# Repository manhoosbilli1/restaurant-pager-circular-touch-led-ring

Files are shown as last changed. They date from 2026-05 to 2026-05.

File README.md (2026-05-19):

# Restaurant Pager — Circular Touch + LED Ring

ESP32-controlled circular restaurant table pager: a central capacitive **TOUCH** pad surrounded by a 16-LED ring of WS2812B addressable RGBs, plus a **MIC** for audio.

Designed in EasyEDA Pro. Sources here are the **KiCad-converted** form produced by `_backup-tooling/epcb_to_kicad.py` and `_backup-tooling/esch_to_kicad_sch.py`. Original EasyEDA `.epro` archive preserved in `source/` for re-editing.

## At a Glance

- **Board size**: 60 × 60 mm, 4-layer
- **Components**: 101 placed, 17× WS2812B-2020 addressable LEDs forming a ring around a central capacitive touch pad
- **Tracks**: 1,051 (top + bottom)
- **Vias**: 288 (0.305 mm drill / 0.61 mm pad)
- **Copper zones**: 18 (GND + power pours)
- **Schematic**: 200 component instances (101 placed + power/test points), 405 wires
- **Status**: Routed and assembled (manufactured version)

## Renders

3D models for **48 of 101 components** come from the LCSC library (fetched via easyeda2kicad). The ESP32-S3 module, JST-PH connectors, USB-C receptacle, MIC package, and LED bodies are visible with real geometry. The remaining components fall back to flat pad placeholders.

### 3D top (controller side)
The labelled side: PWR / STATUS / 5V / GND / CHG / EXT TOUCH / LED OUT / BAT / VBAT / USB / SPKR / 3V3 / BOOT / RESET test points around the **ESP32-S3 module** (top), JST-PH connectors (left + right), USB-C (bottom right).

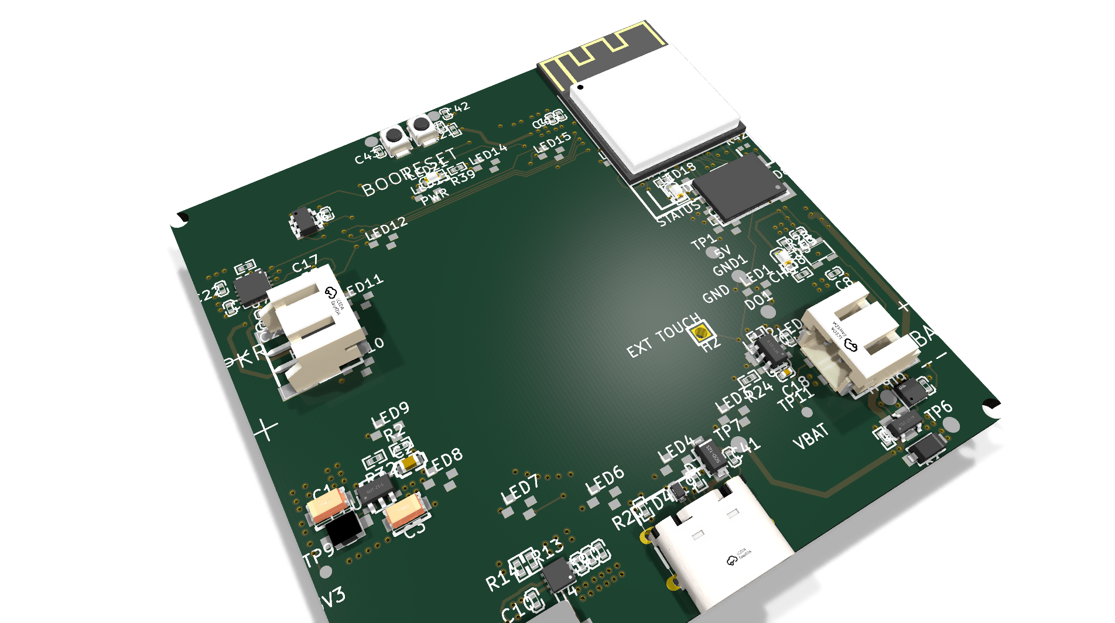
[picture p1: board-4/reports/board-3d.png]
3D top


### 3D bottom (sensor side)
The user-facing side: central round **TOUCH** pad with a ring of 16 WS2812B-2020 RGB LEDs (real 3D bodies visible), **MIC** package on the side, 4 corner mounting/test pads.

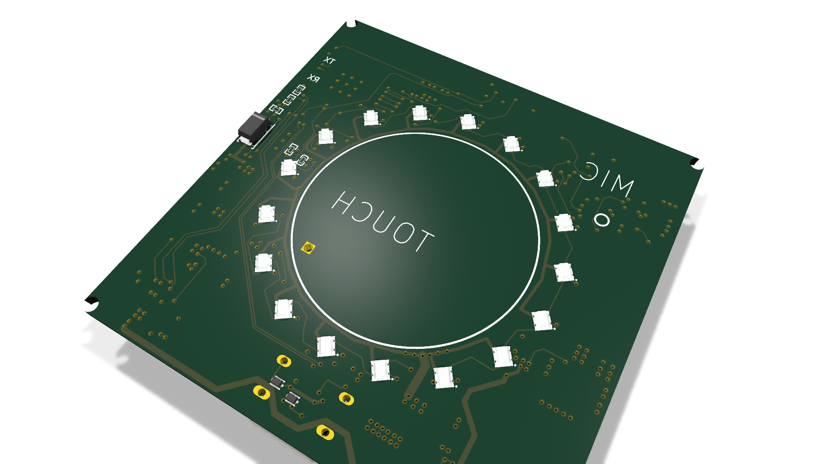
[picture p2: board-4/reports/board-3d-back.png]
3D bottom


## Schematic

Converted from EasyEDA `.esch` to KiCad 10 `.kicad_sch`. **39 of 44 unique component symbols use real geometry parsed from the EasyEDA `.esym` source files** (matching pin counts, pin positions, body rectangles). The remaining 5 fall back to generic KiCad library symbols.

Also extracted from `.esch`: **154 NET labels** on wire endpoints, **17 global labels** (power rails: 3V3, 5V, GND, VBAT, etc.), **27 no-connect markers**, and **405 wire segments** — preserving the exact connectivity of the original.

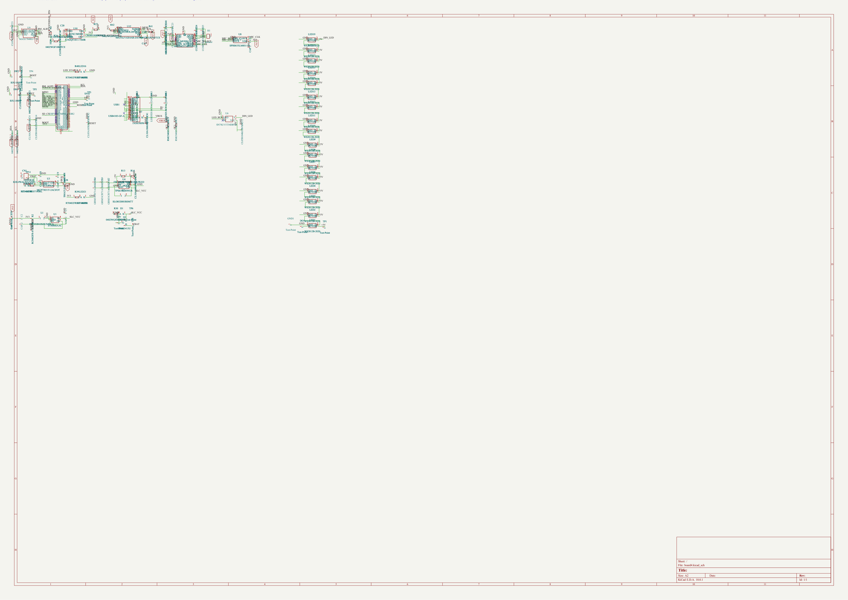
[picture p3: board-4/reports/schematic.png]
Schematic


Full vector PDF: [board-4/reports/schematic.pdf](board-4/reports/schematic.pdf)

## Files

- `board-4/board4.kicad_pcb` — KiCad 10 PCB layout (converted from `.epcb`)
- `board-4/board4.kicad_sch` — KiCad 10 schematic (converted from `.esch`)
- `board-4/reports/board-3d.png`, `board-3d-back.png` — angled raytraced 3D views
- `board-4/reports/pcb-top.svg`, `pcb-bottom.svg` — copper artwork
- `board-4/reports/schematic.pdf`, `schematic.png` — schematic in PDF + raster
- `board-4/reports/bom.csv` — 101-component BOM with MPN-ish library references (most include LCSC codes)
- `board-4/reports/board-stats.json` — KiCad-computed board statistics
- `source/Restaurant table pager circular.epro` — original EasyEDA Pro project archive
- `source/` also holds the source dump if you re-extract; original lives at the .epro zip

## How this repo was produced

The conversion pipeline lives at `_backup-tooling/` in the parent workspace:

```bash
# 1. PCB conversion (EasyEDA Pro .epcb -> .kicad_pcb)
python epcb_to_kicad.py source/extracted/PCB/<pcb-uuid>.epcb \
    -o board-4/board4.kicad_pcb \
    --footprint-dir source/extracted/FOOTPRINT \
    --project-json source/extracted/project.json \
    --title "Restaurant Pager Circular - Board 4"

# 2. Schematic conversion (EasyEDA Pro .esch -> .kicad_sch, KiCad 10 format)
python esch_to_kicad_sch.py source/extracted/SHEET/<sheet-uuid>/1.esch \
    -o board-4/board4.kicad_sch

# 3. Render artifacts via kicad-cli (3D PNGs, copper SVGs, schematic PDF)
kicad-cli pcb render --rotate -30,0,30 --quality high --floor --perspective \
    -w 1920 -h 1080 --side top -o board-4/reports/board-3d.png board-4/board4.kicad_pcb
kicad-cli sch export pdf -o board-4/reports/schematic.pdf board-4/board4.kicad_sch
```

Schematic emitter patterns are based on [eencyclopedia/lib/kicad/fromEditorState.ts](https://github.com/manhoosbilli1) — a hand-rolled, test-covered KiCad 10 writer.

## Caveats (Phase 1 conversion)

- **101/101 components rendered** on PCB (real pad geometry from `.efoo` library + embedded test-point footprints). Some component rotations or silkscreen positions may be slightly off from the original due to coordinate-frame conventions — this is a known issue in the converter, see `_backup-tooling/epcb_to_kicad.py`.
- **Schematic component symbols** are generic KiCad library placeholders, not full visual replicas of the EasyEDA symbols (would need a per-symbol mapping table).
- **Net connectivity** is preserved at the data level (PAD_NET records → KiCad net IDs) but won't pass DRC/ERC as-is.
- The `.epro` archive in `source/` is the authoritative original — re-import to EasyEDA Pro for any active editing.

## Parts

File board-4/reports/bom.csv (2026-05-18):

Designator | LibReference (MPN-ish) | Comment/Value | Footprint | Description
C1 | CA45-A-16V-10uF-K_C185774 | 10uF
CN1 | S2B-PH-SM4-TB(LF)(SN)
C2 | AC0603JRNPO9BN220 | 22pF
C3 | CA45-A-16V-10uF-K_C185774 | 10uF
C4 | 0402ZD106MAT2A | 10uF
C7 | 04026D226MAT2A | 22uF
C8 | 0402X475K100NT | 4.7uF
C9 | 0402X475K100NT | 4.7uF
C10 | 0402ZD106MAT2A | 10uF
C12 | CL05B104KO5NNNC | 100nF
C14 | CL05B104KB54PNC | 100nF
C15 | CL05B104KB54PNC | 100nF
C17 | CT41G-0402-2X1-16V-0.1uF-K(N) | 100nF
C18 | CL05B103KB5NNNC | 10nF
C20 | CL05B104KB54PNC | 100nF
C21 | CL05B104KB54PNC | 100nF
C22 | 0402ZD106MAT2A | 10uF
C23 | CL05B104KB54PNC | 100nF
C24 | 0402N221G500CT | 220pF
C25 | 0402N221G500CT | 220pF
C39 | 04026D226MAT2A | 22uF
C40 | 04026D226MAT2A | 22uF
C41 | 0402ZD106MAT2A | 10uF
C42 | CL05A105KP5NNNC | 1uF
C43 | CL05B104KB54PNC | 100nF
C44 | CT41G-0402-2X1-16V-0.1uF-K(N) | 100nF
D1 | B5819W_C64885
DO1 | Test-Point
D4 | LESD5D5.0CT1G_C41399463
D5 | LESD5D5.0CT1G_C41399463
D6 | LESD5D5.0CT1G_C41399463
D7 | 1N5819HW-7-F
D8 | SMAJ5.0A_C5249616
GND1 | Test-Point
H1 | S2B-PH-SM4-TB(LF)(SN)
H2 | HDR-M_2.54_1x1P
L1 | FTC252012S2R2MBCA | 2.2uH
LED1 | WS2812B-2020
L2 | SLO0520H1R0MTT | 1uH
LED2 | WS2812B-2020
LED3 | WS2812B-2020
LED4 | WS2812B-2020
LED5 | KT-0603R
LED6 | WS2812B-2020
LED7 | WS2812B-2020
LED8 | WS2812B-2020
LED9 | WS2812B-2020
LED10 | WS2812B-2020
LED11 | WS2812B-2020
LED12 | WS2812B-2020
LED13 | WS2812B-2020
LED14 | WS2812B-2020
LED15 | WS2812B-2020
LED16 | KT-0603R
LED17 | WS2812B-2020
LED18 | WS2812B-2020
LED19 | WS2812B-2020
LED21 | KT-0603R
Q1 | DMG3415U
R2 | RC0402FR-07100KL
R13 | AC0402FR-07732KL
R14 | CRCW0402100KFKED
R17 | 0402WGJ0103TCE
R18 | 0402WGJ0103TCE
R19 | RMC04025.1K5%N
R20 | RMC04025.1K5%N
R21 | 0402WGJ0103TCE
R24 | SCR0402F10K
R27 | SCR0402J0R
R28 | RC0402FR-071KL
R30 | 0402WGJ0103TCE
R32 | RC0402FR-0722K1L
R35 | 0402WGF1004TCE
R38 | RT0402FRE07140RL
R39 | RT0402FRE07140RL
R40 | RT0402FRE07140RL
R41 | 0402WGJ0103TCE
R42 | 0402WGJ0103TCE
SW1 | B3U-1000P_C231329
SW2 | B3U-1000P_C231329
TP1 | Test-Point
TP3 | Test-Point
TP4 | Test-Point
TP5 | Test-Point
TP6 | Test-Point
TP7 | Test-Point
TP8 | Test-Point
TP9 | Test-Point
TP10 | Test-Point
TP11 | Test-Point
U1 | SY8088IAAC
USB1 | USB4105-GF-A
U3 | MCP73831T-2ACI/OT
U4 | TPS61022RWUR
U5 | ESP32-S3-MINI-1-N4R2
U6 | SN74LV1T34DBVR_RF v1.0
U7 | MAX98357AETE+T
U8 | SPH0655LM4H-1-8
U9 | MAX17048G+T10
U10 | AT42QT1011-TSHR
U12 | MX35LF1GE4AB-Z4ITR

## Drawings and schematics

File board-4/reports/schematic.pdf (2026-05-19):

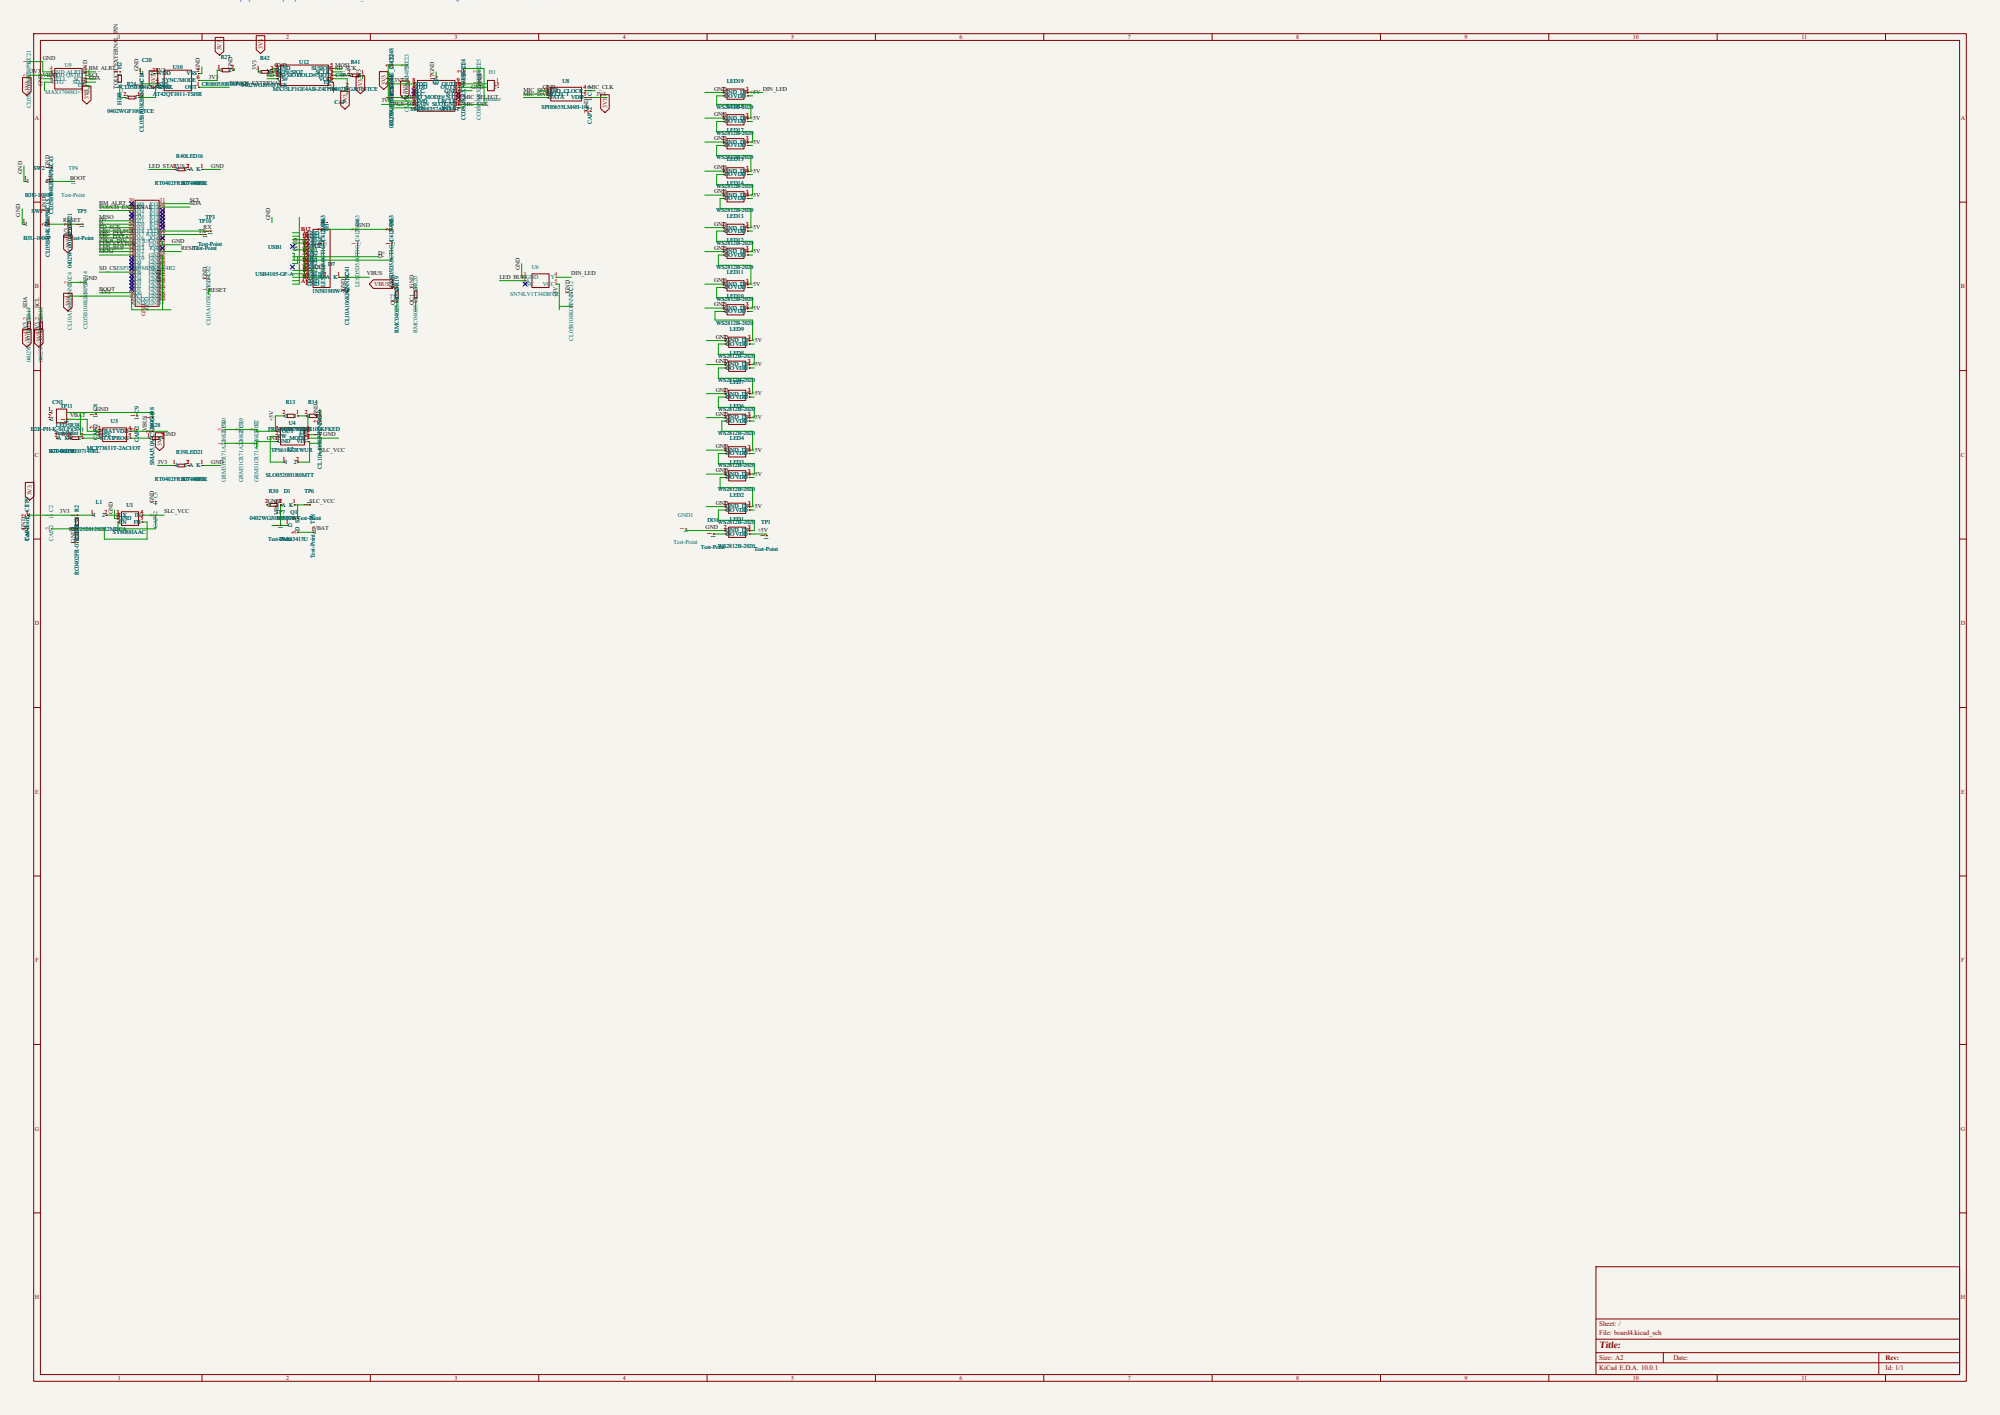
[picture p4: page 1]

1 TP4 Test-Point CS# 1SO/SIO1 2WP#/SIO2 3GND 4 SI/SIO05 SCLK6 HOLD#/SIO37 VCC8 EP9 U12 MX35LF1GE4AB-Z4ITR DIN 1GAIN_SLOT 2GND 3SD_MODE# 4N.C. 5

2 LED19 WS2812B-2020 DO 1GND 2 DI3 VDD4 LED18 WS2812B-2020 DO 1GND 2 DI3 VDD4 LED17 WS2812B-2020 DO 1GND 2 DI3 VDD4 C17 CAP 1

2 LED15 WS2812B-2020 DO 1GND 2 DI3 VDD4 LED14 WS2812B-2020 DO 1GND 2 DI3 VDD4 LED13 WS2812B-2020 DO 1GND 2 DI3 VDD4 LED12 WS2812B-2020 DO 1GND 2 DI3 VDD4 LED11 WS2812B-2020 DO 1GND 2 DI3 VDD4 LED10 WS2812B-2020 DO 1GND 2 DI3 VDD4 LED9 WS2812B-2020 DO 1GND 2 DI3 VDD4 LED8 WS2812B-2020 DO 1GND 2 DI3 VDD4 LED7 WS2812B-2020 DO 1GND 2 DI3 VDD4 LED6 WS2812B-2020 DO 1GND 2 DI3 VDD4 LED4 WS2812B-2020 DO 1GND 2 DI3 VDD4 LED2 WS2812B-2020 DO 1GND 2 DI3 VDD4 LED1 WS2812B-2020 DO 1GND 2 DI3 VDD4 TP1 Test-Point 1

1 GND1 Test-Point DO 1GND 2 DI3 VDD4 LED3 WS2812B-2020 DO 1GND 2 DI3 VDD4 LED2 WS2812B-2020 DO 1GND 2 DI3 VDD4 LED12 WS2812B-2020

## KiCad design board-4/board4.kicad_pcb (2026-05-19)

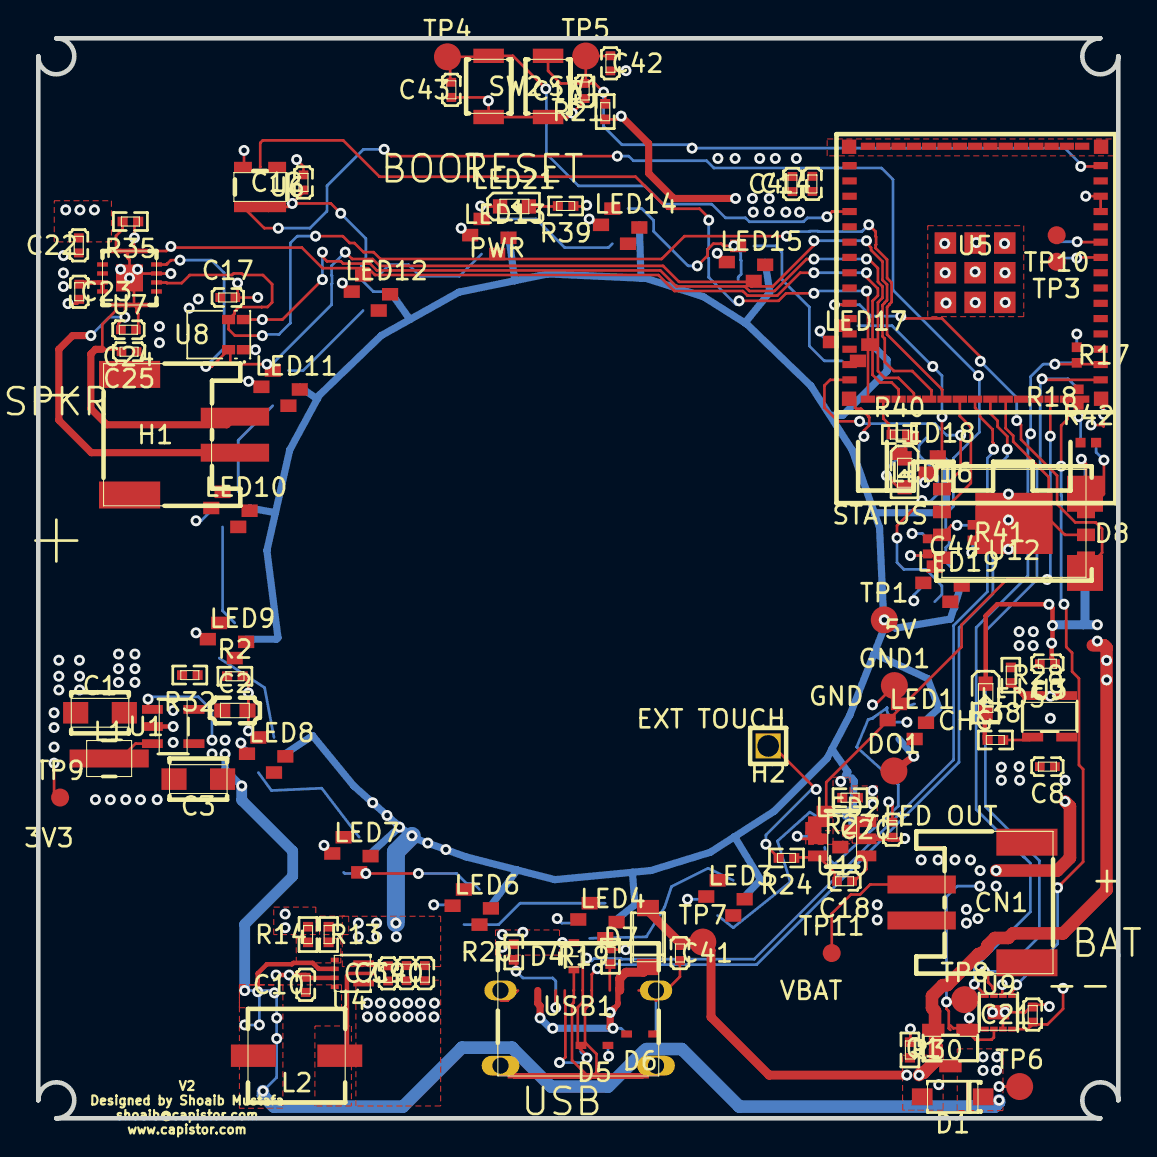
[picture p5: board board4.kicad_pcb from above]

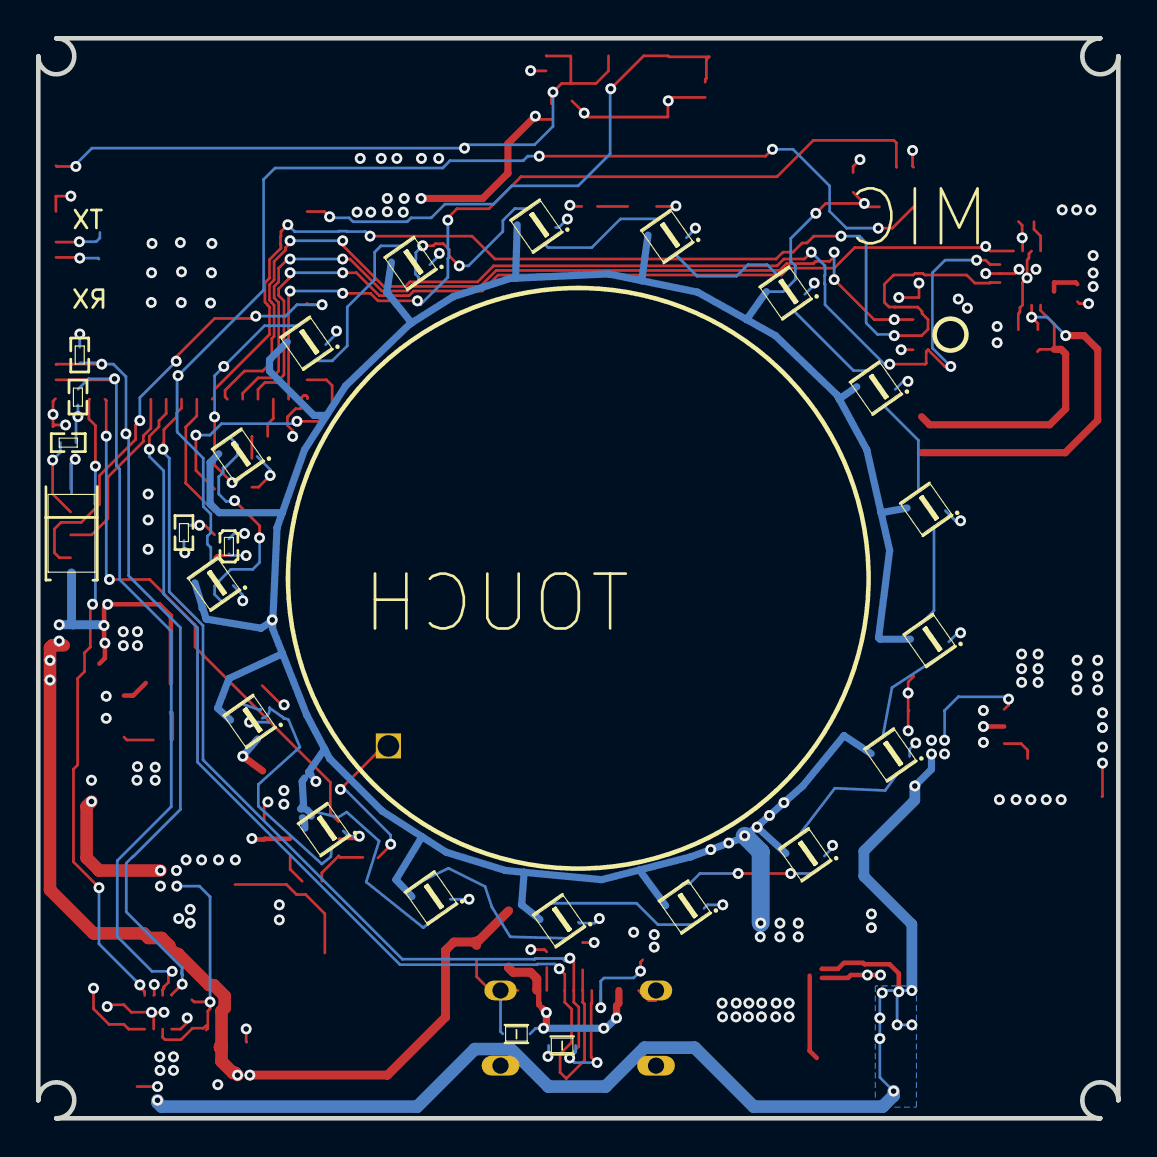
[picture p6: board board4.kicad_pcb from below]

Board: 2 copper layers, 60.0 x 60.0 mm, 101 parts (27 on the bottom side), 64 nets.

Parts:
C1, C2, C3, C4, C7, C8, C9, C10, C12, C14, C15, C17, C18, C20, C21, C22, C23, C24, C25, C39, C40, C41, C42, C43, C44: FP
CN1: FP
D1, D4, D5, D6, D7, D8: FP
DO1: Test-Point-0.5mm
GND1: Test-Point-0.5mm
H1, H2: FP
L1, L2: FP
LED1, LED2, LED3, LED4, LED5, LED6, LED7, LED8, LED9, LED10, LED11, LED12, LED13, LED14, LED15, LED16, LED17, LED18, LED19, LED21: FP
Q1: FP
R2, R13, R14, R17, R18, R19, R20, R21, R24, R27, R28, R30, R32, R35, R38, R39, R40, R41, R42: FP
SW1, SW2: FP
TP1, TP3, TP4, TP5, TP6, TP7, TP8, TP9, TP10, TP11: Test-Point-0.5mm
U1, U3, U4, U5, U6, U7, U8, U9, U10, U12: FP
USB1: FP

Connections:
3V3: C1.1, C2.2, C4.2, C14.2, C17.2, C20.2, C21.1, C22.2, C23.2, C44.1, L1.1, R2.2, R17.2, R18.2, R21.2, R27.1, R35.1, R39.1, R41.1, R42.1, TP9.1, U5.3, U7.2, U7.7, U7.8, U8.5, U9.3, U9.9, U10.5, U10.6, U12.8
$1N5324: C18.1, U10.4
$1N5325: C18.2, R24.1, U10.3
$1N5342: R35.2, U7.4
$1N5353: C24.2, H1.2, U7.10
$1N5354: C25.2, H1.1, U7.9
$1N5410: R28.1, U3.5
$1N5412: LED5.1, R38.1
$1N5413: R38.2, U3.1
$1N5423: L1.2, U1.3
$1N5430: L2.1, U4.2
$1N5433: R13.1, R14.2, U4.4
$1N5458: LED18.3, LED19.1
$1N5459: LED17.3, LED18.1
$1N5464: LED15.3, LED17.1
$1N5465: LED14.3, LED15.1
$1N5470: LED13.3, LED14.1
$1N5471: LED12.3, LED13.1
$1N5476: LED11.3, LED12.1
$1N5477: LED10.3, LED11.1
$1N5482: LED9.3, LED10.1
$1N5483: LED8.3, LED9.1
$1N5488: LED7.3, LED8.1
$1N5489: LED6.3, LED7.1
$1N5494: LED4.3, LED6.1
$1N5495: LED3.3, LED4.1
$1N5500: LED2.3, LED3.1
$1N5501: LED1.3, LED2.1
$1N5535: DO1.1, LED1.1
$1N5564: C2.1, R2.1, R32.1, U1.5
$1N5565: D6.2, D7.2, USB1.A4, USB1.A9, USB1.B4, USB1.B9
$1N19227: LED21.2, R39.2
$1N19266: LED16.2, R40.2
$1N28187: R41.2, U12.7
$1N31093: R42.2, U12.3
+5V: C7.1, C12.2, C39.1, C40.1, LED1.4, LED2.4, LED3.4, LED4.4, LED6.4, LED7.4, LED8.4, LED9.4, LED10.4, LED11.4, LED12.4, LED13.4, LED14.4, LED15.4, LED17.4, LED18.4, LED19.4, R13.2, TP1.1, U4.3, U6.5
BM_ALRT: U5.29, U9.5
BOOT: C43.1, SW2.2, TP4.1, U5.4
CC1: R20.2, USB1.A5
CC2: R19.2, USB1.B5
D+: D4.2, U5.24, USB1.A6, USB1.B6
D-: D5.2, U5.23, USB1.A7, USB1.B7
DIN_LED: LED19.3, U6.4
GND: C1.2, C3.2, C4.1, C7.2, C8.2, C9.2, C10.1, C12.1, C14.1, C15.2, C17.1, C20.1, C21.2, C22.1, C23.1, C24.1, C25.1, C39.2, C40.2, C41.1, C42.1, C43.2, C44.2, CN1.1, D4.1, D5.1, D6.1, D8.2, GND1.1, LED1.2, LED2.2, LED3.2, LED4.2, LED6.2, LED7.2, LED8.2, LED9.2, LED10.2, LED11.2, LED12.2, LED13.2, LED14.2, LED15.2, LED16.1, LED17.2, LED18.2, LED19.2, LED21.1, R14.1, R19.1, R20.1, R27.2, R28.2, R30.2, R32.2, SW1.1, SW2.1, U1.2, U3.2, U4.1, U4.6, U5.1, U5.2, U5.42, U5.43, U5.46, U5.47, U5.48, U5.49, U5.50, U5.51, U5.52, U5.53, U5.54, U5.55, U5.56, U5.57, U5.58, U5.59, U5.60, U5.GND, U6.3, U7.3, U7.11, U7.15, U7.17, U9.1, U9.4, U9.6, U10.2, U12.4, U12.9, USB1.1, USB1.A1, USB1.A12, USB1.B1, USB1.B12
LED_BUF: U5.16, U6.2
LED_STATUS: R40.1, U5.17
MIC_CLK: U5.20, U7.16, U8.4
MIC_DATA: U5.19, U8.1
MIC_SELECT: U5.21, U7.14, U8.2
MISO: U5.25, U12.2
MOSI: U5.15, U12.5
RESET: C15.1, C42.2, R21.1, SW1.2, TP5.1, U5.45
RX: TP3.1, U5.39
SCL: R18.1, U5.31, U9.7
SDA: R17.1, U5.32, U9.8
SD_CS: U5.10, U12.1
SD_SCK: U5.22, U12.6
SLC_VCC: C3.1, C10.2, D1.1, L2.2, Q1.2, TP6.1, U1.1, U1.4, U4.5, U4.7
SPKR_DIN: U5.18, U7.1
TOUCH_EXTERNAL: U5.28, U10.1
TOUCH_EXTERNAL_PIN: H2.1, R24.2
TX: TP10.1, U5.40
VBAT: C8.1, CN1.2, Q1.3, TP8.1, TP11.1, U3.3, U9.2
VBUS: C9.1, C41.2, D1.2, D7.1, D8.1, LED5.2, Q1.1, R30.1, TP7.1, U3.4

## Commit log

2026-05-18 Replace Altium-ASCII parse with full KiCad conversion (PCB + schematic + renders, single board)
    [bisect.kicad_pcb, board4.kicad_pcb, board4.kicad_sch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]
2026-05-18 Clean up: remove debug test files
    [t_arc.kicad_pcb, t_fp1.kicad_pcb, t_seg.kicad_pcb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]
2026-05-18 Remove leftover test/bisect files
    [bisect.kicad_pcb]
2026-05-18 Schematic: use real .esym geometry — 39 of 44 lib_symbols built from EasyEDA source (proper pins, no more red placeholders)
    [board4.kicad_sch]
2026-05-19 PCB: negate component rotation to compensate for math/screen frame Y-reflection — LED ring and IC pad orientations now uniform
    [board4.kicad_pcb]
2026-05-19 Add LCSC component library: 48 components now render with real 3D bodies. Schematic adds 154 NET labels + 17 global labels + 27 no_connects from .esch (was missing).
    [board4.kicad_pcb, board4.kicad_sch]
2026-05-19 PCB: add silk arc handling, restrict SVG export to visible layers (no F.Mask). 3D model rotation kept at 0,0,0 — per-model rotation varies and global offset breaks more than it fixes.
    [board4.kicad_pcb]
2026-05-19 Schematic: device-table fallback for symbol UUIDs — 44/44 components now use real .esym geometry (was 39/44, the 5 missing had no explicit Symbol attr). Wire endpoints should now land on real pin off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
    [board4.kicad_sch]
